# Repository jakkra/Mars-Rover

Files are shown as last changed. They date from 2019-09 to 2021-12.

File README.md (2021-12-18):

<div align="center">
  <h1>Mars Rover</h1>
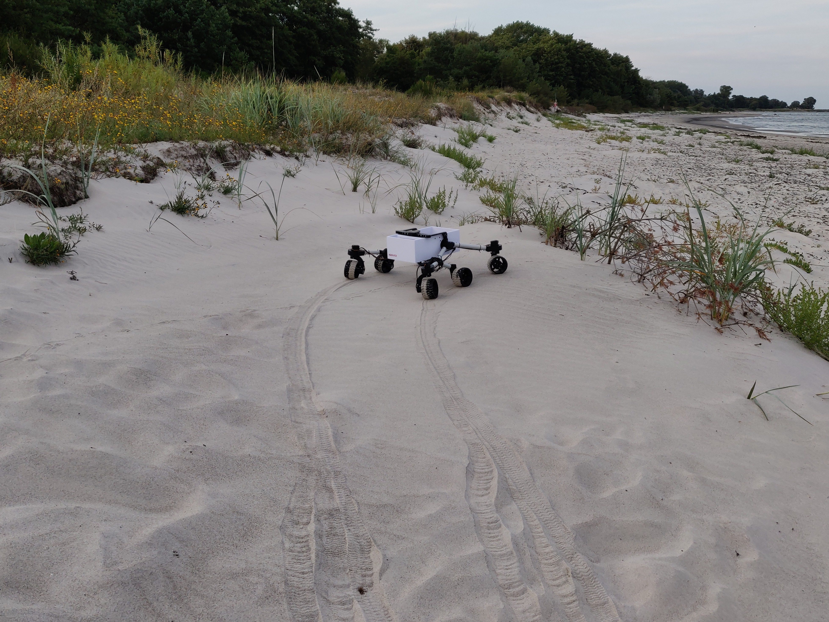
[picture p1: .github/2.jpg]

<sub>
  Curiosity/Perseverance inspired Rover
</sub>
</div>

---

Controller for driving the Rover found here [https://github.com/jakkra/RoverController](https://github.com/jakkra/RoverController).
## CAD model
The whole Fusion 360 project can be found in the CAD folder, download the .f3z file and open it in desktop Fusion 360. 

The CAD render images are more up to date than the real images of the rover, for example some cosmetics have been added and the high gain antenna which can be rotated by a servo.

### Wheels
There are two options for wheeles, either original Curiosity style wheels that print in one piece. Or Mars 2020 style wheels that print in two parts where outer part can be printed in flexibale plastic such as TPU. The rover_2020_wheel_flex.f3d wheels are preferred if your printer can print in TPU as they provide way more grip.

## Driving
There are 3 ways to drive the Rover right now:
- LoRa
- Websockets
- Generic RC Transmitter

By moving a 3 way switch on the rover, the startup mode can be choosen; WiFi station + LoRa, LoRa only or WiFi AP (when using website hosted on the Rover, see data folder).
[Here](https://github.com/jakkra/RoverController) is my controller supporting both LoRa and websocket control of the Rover.

### Telematics
Rover will automatically send telematics data as soon as someone connects to the websocket server or over LoRa if Rover is being controlled ove LoRa.

## Hardware
- 6 12V 60 RPM DC motors, one in each wheel (https://github.com/jakkra/Mars-Rover/issues/6)
- 2 brushless ESC's one for each side (3 motors)
- Lots of (12, one for each servo) 12V to 5V switching voltage regulators
- 4 servos (MG946R/MG996R) on each corner wheel to steer.
- 6 Servos (MG946R) in the arm for 6-DOF. Poweded by a 3S battery. 
- 2 servos (MG946R/MG996R) for the head.
- 6 Channel RC receiver and transmitter
- 6 Motor shaft adapters https://www.pololu.com/product/1081
- Some Round Metal Servo Arm 25T Disc Horns.
- MCU (ESP32)
- 3S battery
- Standard PVC pipe with inner diameter of 23.40 mm and outer diameter 25 mm.
- Lots of screws and bolts, mostly M3, but some M4's too.
- Two kinds of bearings: 5x 608ZZ and 5x 25mm SKF 6005
- Check the Fusion360 project for more details.
- Cable madness is TODO to fix (temporary fixed by hiding it under the "lid")

## Building
There is no manual, but downloading the CAD model and browsing through it should get you started. Browse through both open and closed issues for help. Feel free to open an issue if you have a question. 

## Images
Videos:
- Showing the boogie mechanism in action [https://imgur.com/4UIsRLl](https://imgur.com/4UIsRLl) 
- Arm [https://imgur.com/KY5ioLb](https://imgur.com/KY5ioLb)
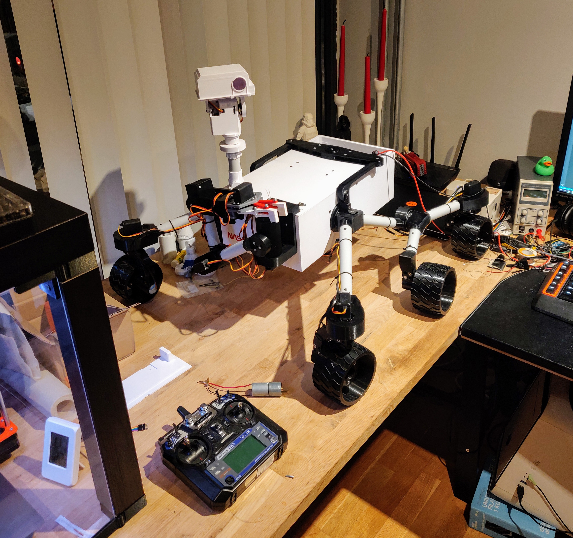
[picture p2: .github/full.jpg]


<p float="left">


</p>
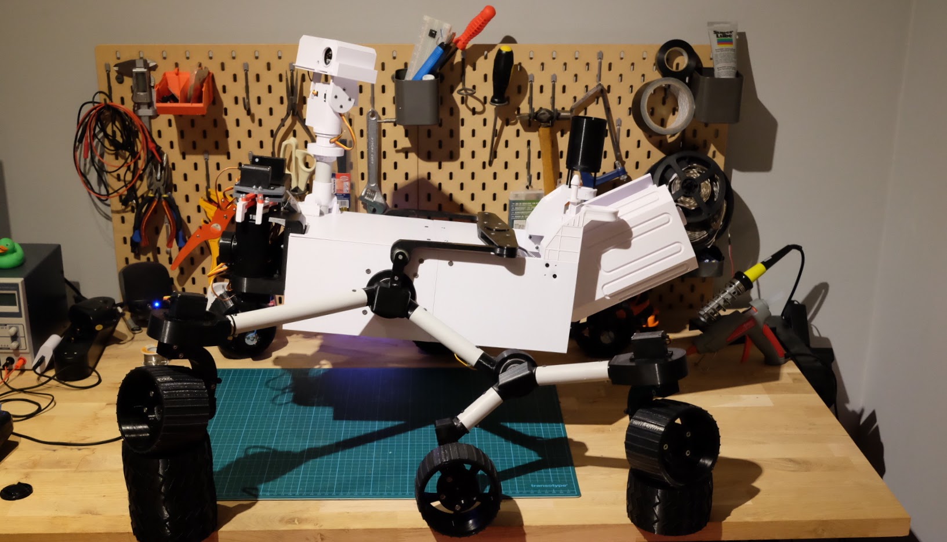
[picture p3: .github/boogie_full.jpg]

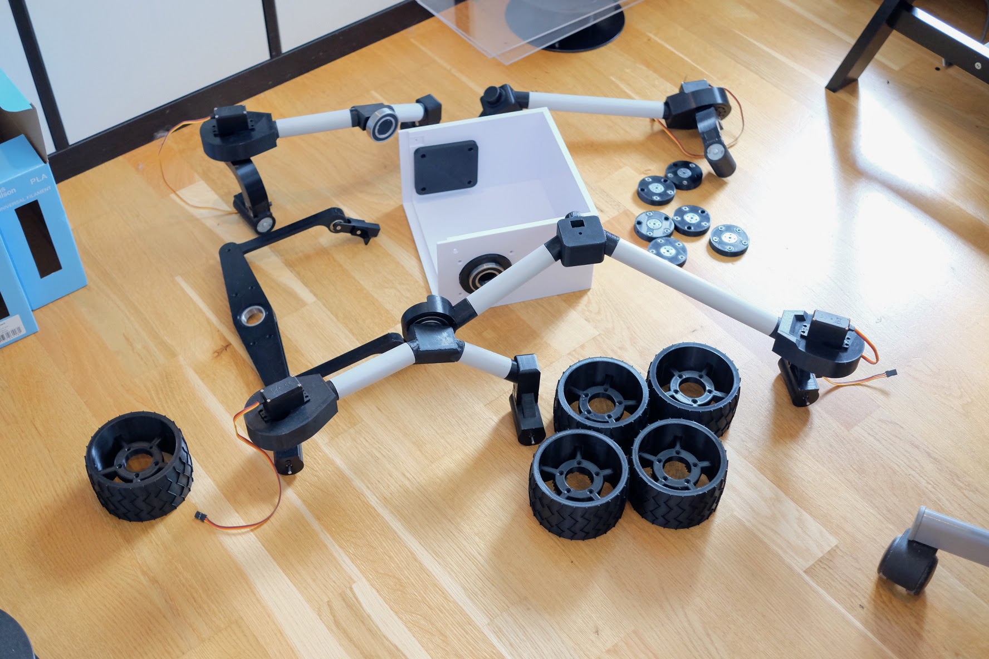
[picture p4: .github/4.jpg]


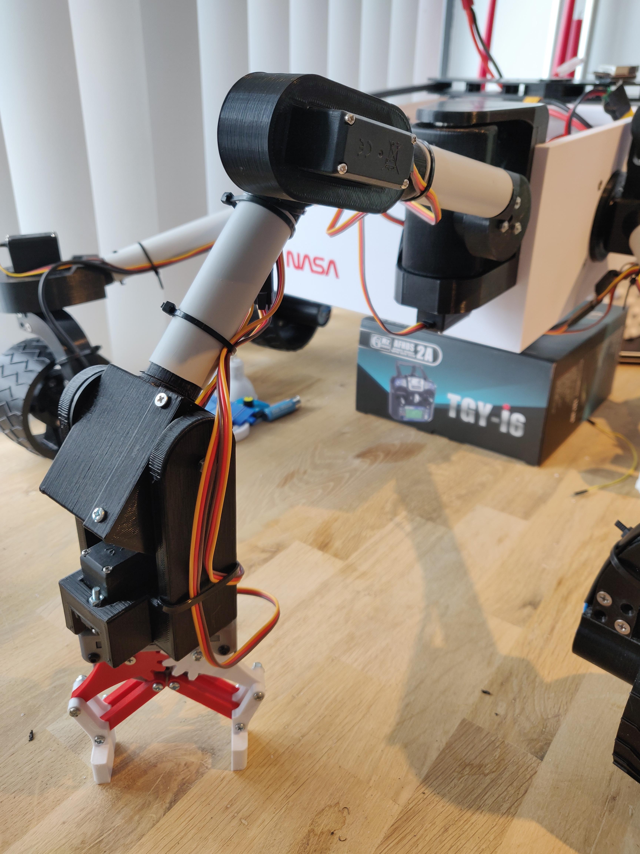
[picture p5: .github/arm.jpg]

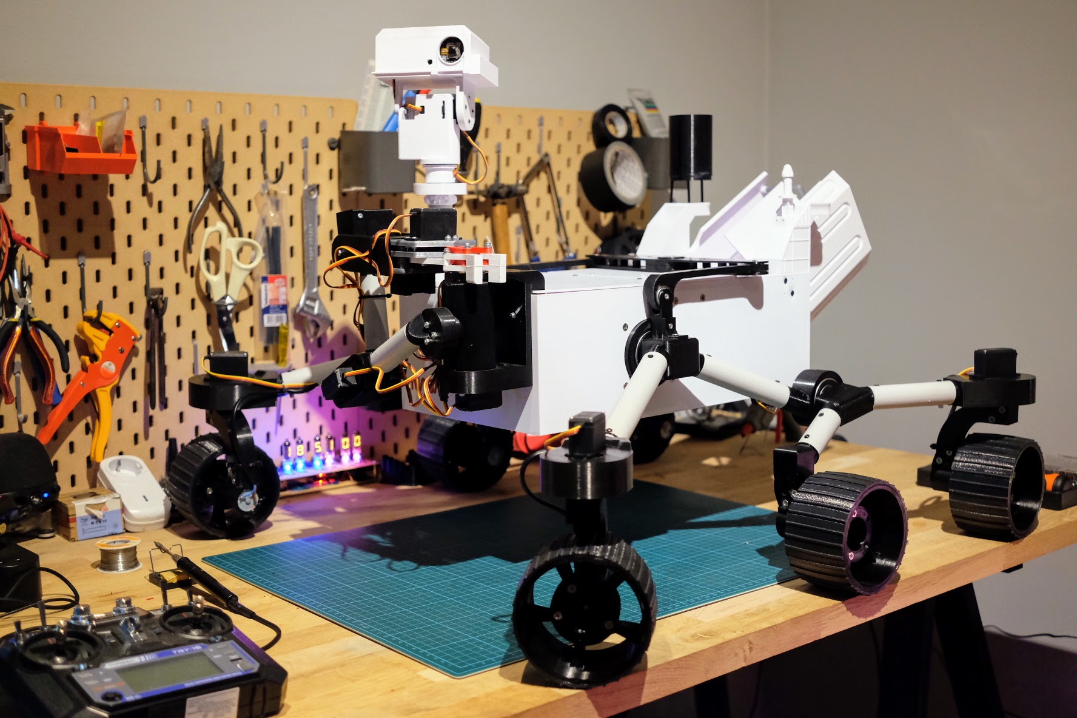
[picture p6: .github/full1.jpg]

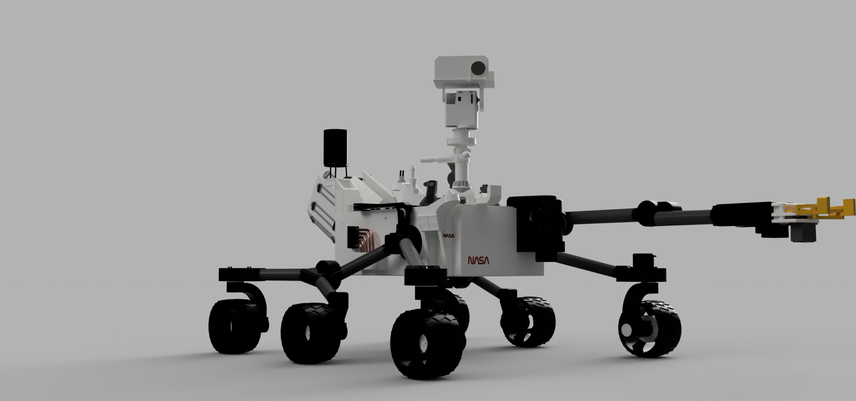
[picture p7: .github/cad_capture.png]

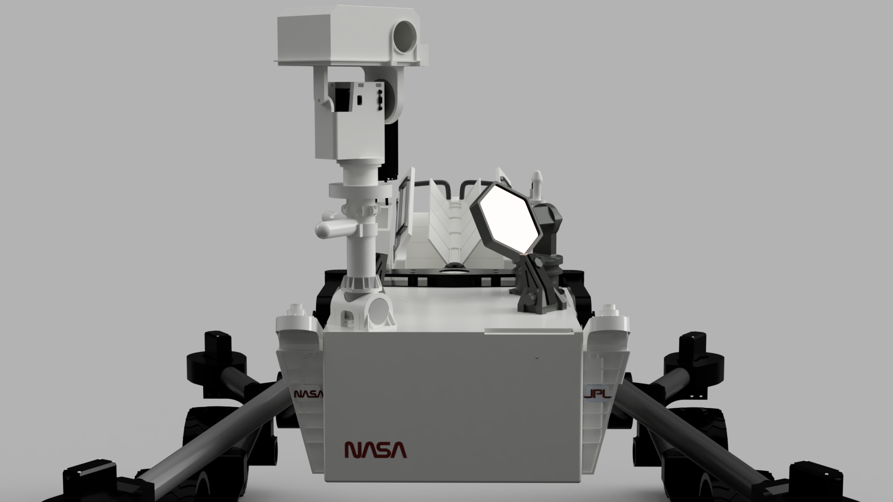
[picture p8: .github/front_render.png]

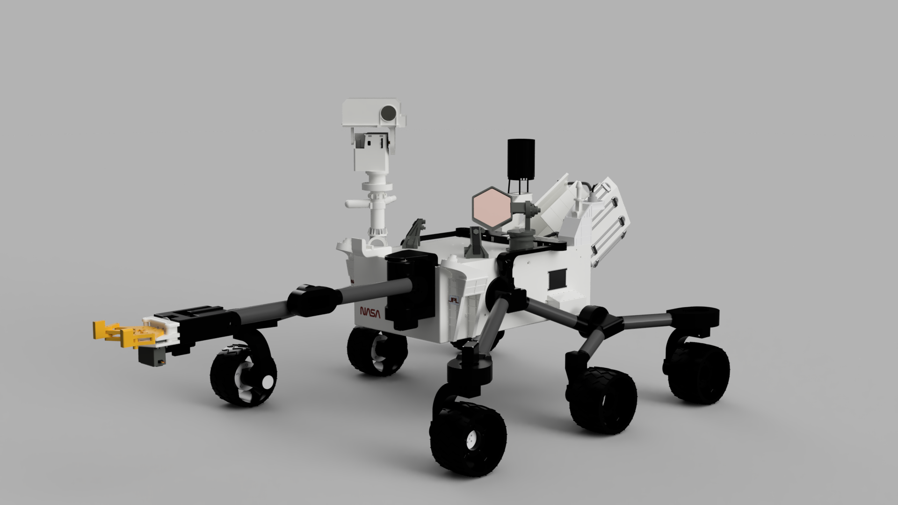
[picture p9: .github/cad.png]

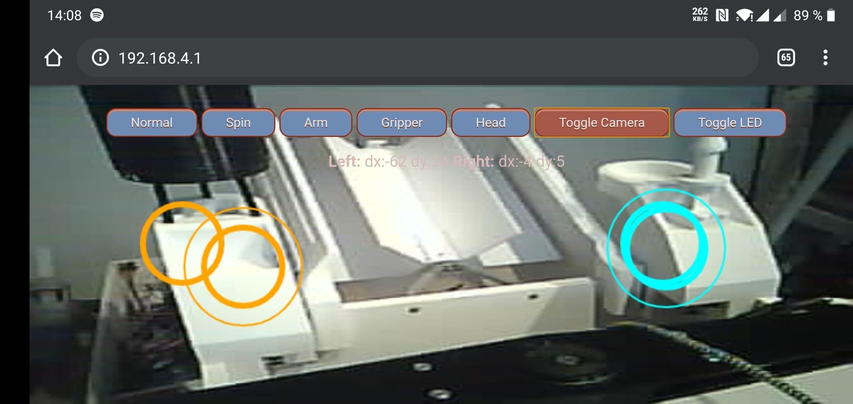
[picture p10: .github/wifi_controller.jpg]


## Driving Modes
There are three ways to drive the rover. Either using a RC controller, LoRa or from a website hosted on the ESP32.
RC controller is deafult, but as soon as someone connects to the ESP32 AP and a websocket is created, the RC controller or LoRa will be overriden by the WiFi controller.
The website functionality is just as basic as the RC controller right now, but the plan is to add more advanced functionality to the website which is not possible to do on the RC controller.
On the RC Transmitter I use two joysticks for channels 1-4 for, and two switches for channel 5-6.
Joysticks are used both for steering the Rover and for moving each axis of the arm.
When switch1 is:
- LOW: joysticks are used for driving the rover
- MID: Wheels will be set correct angles for the rover to be able to rotate on the spot by running each side of wheels in opposite direction. The direction is descided by the steer joystick.
- HIGH: Arm mode, the two joysticks are used for moving axis 1-4 on the arm. Switch2 is used to switch between moving axis 1-4 and axis 5-6 (the gripper). This will be changed in the future, steering each axis manually is not really a good way, inverse kinematics is TODO.

## Arm
Currently arm is just pretty much mapped to controls on the Controller, this is not really useful, so TODO.

## Misc

### Uploading Controller page to Spiffs
```
pio run -t uploadfs
```

### Decoding crashes
```
xtensa-esp32-elf/bin/xtensa-esp32-elf-addr2line.exe -pfiaC -e /c/Users/ijakk_000/Documents/Rover-code/.pio/build/esp-wrover-kit/firmware.elf 0x00000000:0x3ffb5c60 ...
```

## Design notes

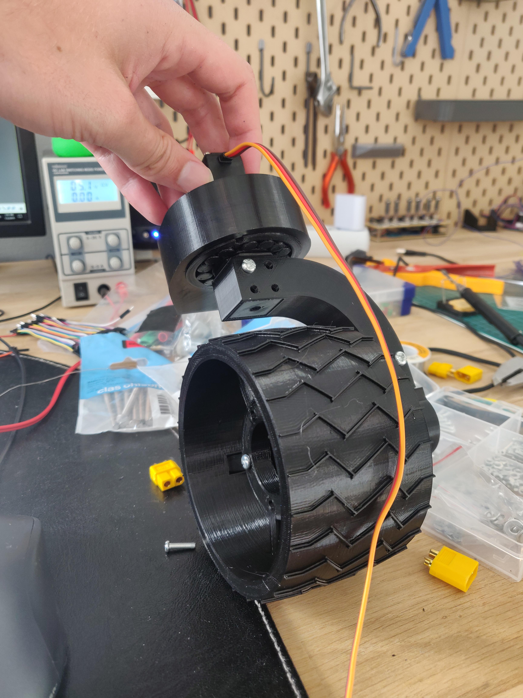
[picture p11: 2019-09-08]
.github/bearing_wheel.jpg

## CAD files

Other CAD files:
CAD/rover_2020_wheel_flex.f3d

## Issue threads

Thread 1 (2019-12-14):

Tubing

fabriziofiorucci, 2019-12-14:
Hello, thank you for sharing this very interesting project: far as I can see the rocker bogie tubing is not printed but looks like standard pvc tubing: what thickness did you select?
Thank you

fabriziofiorucci, 2019-12-14:
Solved! Measured from the f3d body

jakkra, 2019-12-14:
Hi thanks!

I was just about to send you this:
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
Yes it's some standard PVC pipe I found to save some printing time.
In Fusion 360 modify -> change parameters you can see the diameters.
I do hover doubt it's going to work just changing the setting there.

fabriziofiorucci, 2019-12-14:
Thank you! Just started printing the whole rover using asa-x filament

jakkra, 2019-12-14:
Awesome, good luck! I'm sure thats better than the cheap standard PLA I have printed with.

hoonkai, 2020-04-27:
@jakkra Hi What sort of adhesive did you use to attach the PVC and the parts together?

fabriziofiorucci, 2020-04-27:
@hoonkai in case this can help, please see here https://github.com/jakkra/Mars-Rover/issues/12#issuecomment-620130493

jakkra, 2020-04-27:
Hi @hoonkai, the fit is pretty tight but still needs something more to make it 100%, I just drilled a hole straight through and put a screw through like this:
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

Closed 2019-12-14.

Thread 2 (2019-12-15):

Electronics schematics

fabriziofiorucci, 2019-12-15:
Hello, could you share the electronics schematics?
I’m building the electronics based on a raspberry zero and that would come handy.

Thanks!

jakkra, 2019-12-15:
I did draw a not very detailed, but good enough psuedo schematic a while ago. This was from before I added the arm and head. Now I have a I2C servo expander which all servos are connected to for saving pins on the ESP32.
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

fabriziofiorucci, 2019-12-15:
That’s a good starting point: what ESCs do you use?

fabriziofiorucci, 2019-12-15:
I have a fully working design using 6 L298N drivers for the six dc motors, I’m evaluating whether to switch to ESCs

jakkra, 2019-12-15:
I'm using 2 of those with 3 motors connected to each of them
https://hobbyking.com/en_us/hobbyking-x-car-45a-brushed-car-esc.html
So I don't have control of each motor individually, only each side.
I don't see a problem using 6 L298N as long as your DC motors doesn't draw more than 2A under load.

fabriziofiorucci, 2019-12-15:
Thanks: I actually am revamping a former rover I built using aluminium instead of plastic, and a lead acid battery instead of LiPO, with the aim of getting a self guided rover using a control software written in Java. Spare time permitting I might upload some contribution to add distance sensors, lidar etc.

jakkra, 2019-12-15:
Awesome! I'll also add more sensors after I finish the designing and printing the "back" parts of the rover.

I'm thinking of giving https://nasa.github.io/openmct/ a try for ground control software (the UI). I'm also looking for a new radio to get better range and to be able to stream low res video from ~1000m distance. Yet to find a suitable radio technology.

fabriziofiorucci, 2019-12-15:
The openmct project looks quite interesting: on my existing rover I added a GPS receiver and a digital compass and accelerometer, they work quite fine. By saving weight switching from aluminium to ASA and from lead battery to LiPO I might be able to put more stuff on it.
I'm experimenting a bit with LoRA for long range telemetry, but it's way too slow for video streaming, please keep me posted on your findings in that area.

fabriziofiorucci, 2020-01-13:
Hello, for the sake of curiosity, what kind of DC-DC stepdown converter do you use for servos? I'm running on MG996R that have a stall current of ~2.5A so I was wondering, additionally, if you're using one stepdown converter per servo or what else.

Thank you

jakkra, 2020-01-13:
Hi, I'm using variable buck converters like those: https://www.amazon.com/dp/B01MQGMOKI/ref=psdc_10967761_t1_B0758ZTS61
One for each servo (which is kind of a pain)

fabriziofiorucci, 2020-01-13:
Thank you!

fabriziofiorucci, 2020-03-23:
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

Electronics work in progress...

- main board with Raspberry Zero, GPS receiver, magnetometer/accelerometer and ADC for distance sensors
- rocker bogie board with PWM controller for steering servos and control logic for L298N boards

jakkra, 2020-03-24:
Looking good! I finished re-routing my wires so now everything is inside. Currently in progress building a controller using Lora.

fabriziofiorucci, 2020-03-24:
LoRa is in my todo list: will you use it for both control and telemetry? Would you mind sharing some details? I guess you’ll use arduino/wemos, I’ll try the Raspberry way

jakkra, 2020-03-25:
My plan is to use it both for control and telemetry, however I have not yet experimented to see how much the lag is. The idea is to use WiFi control when the rover is close and  switch over to Lora when range increases. I'm going to use two TTGO LORA32, replacing the ESP32 dev kit in the Rover with this board with an ESP32 + Lora transceiver and the other board will be in the controller.

fabriziofiorucci, 2020-03-25:
That sounds really interesting. Please keep us posted!

fabriziofiorucci, 2020-03-29:
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

main board and rocker bogie board assembled and tested, ready to be installed

fabriziofiorucci, 2020-04-03:
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

Ready for testing

jakkra, 2020-04-07:
Looks clean! My current progress:
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
Will have a tablet holder on top also for telematics display.

fabriziofiorucci, 2020-04-07:
it looks great! Will you share the f3d model?

jakkra, 2020-04-08:
Of courese!

fabriziofiorucci, 2020-04-08:
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

My high level electronics design, based on Raspberry Zero WH and I2C everywhere.

fabriziofiorucci, 2020-04-24:
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

Arm and head control board

fabriziofiorucci, 2020-04-24:
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

Closed 2020-04-26.

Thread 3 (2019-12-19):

Steering ball bearing - best way to print

fabriziofiorucci, 2019-12-19:
Hello,

what's the best way to print the steering ball bearing? (see image) all in one print? body by body? I'm thinking to give it a try with 0.12 layer thickness and 30% infill. Did you print it or buy a ready-made one?

Thank you

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

jakkra, 2019-12-19:
Best way to print is like that. I printed with 0.2mm layer height. The infill I don't remember, but 30% sound ok. You might need to modify some clearences depending on your printer. I had to experiment a few times to get it as "stiff" but still rotating as possible. I think I have this bearing in a spearate Fusin360 project where you can modify some parameters. I'll do that when I get home tonight. But give it a try with current setup, it might work good for you.

fabriziofiorucci, 2019-12-19:
Thank you for the details, I’m printing on a creality ender 3, I’ll give it a try tonight.

fabriziofiorucci, 2019-12-20:
Hello again, would you have by chance che fusion project that allows changing clearances? I tried a few prints fiddling with slicer parameters with no success.
Thank you

jakkra, 2019-12-21:
Rename extention to .f3d from .txt as GitHub doesn't allow all file formats to be uploaded.
This is the bearing sketch, you can edit the parameters in the menu modify -> change parameters.
The base comes from thingiverse, but don't remember exact which thing. But here's the sketch.
[608zz10.txt](https://github.com/jakkra/Mars-Rover/files/3991388/608zz10.txt)

fabriziofiorucci, 2019-12-21:
Great, thank you! Meanwhile I’m at 25% of the overall rover body and rocker print. Hope to get the metal ball bearings soon. As soon as the electronics are fit I’ll post some more details.

jakkra, 2019-12-21:
Awesome, good luck!

Closed 2020-01-07.

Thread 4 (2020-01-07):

Best support type to slice & print body

fabriziofiorucci, 2020-01-07:
Hello,

I'm proceeding with all prints, and when it comes to the body I wonder what's the most efficient support type to use when slicing stl files: I'm using Cura and I usually use the default line with 10% spacing. Any hint here/what have you used?

Thank you

jakkra, 2020-01-07:
I'm using Slic3r/PrusaSlicer, for supports I have just used the default ones in my slicer, so can't help you with which are best in Cura. Most parts don't need supports or just need some very simple ones. If you can give me a specific part, I can probably figure out how I printed it and send a image from my slicer.

fabriziofiorucci, 2020-01-07:
Hi, thank you. Most parts are perfectly designed to require a minimum amount of supports (good job!). The only parts I would need a hint is the main body (rover_body_front and the back part), it's quite large and I would like to minimize filament waste by optimizing the (large) support area.

jakkra, 2020-01-07:
I'll be home in an hour ish, will send you some images then.

fabriziofiorucci, 2020-01-07:
Thank you!

jakkra, 2020-01-07:
No supports needed for the front, printed fine on my MK3, should be fine on your Ender 3 too.
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
Only required supports for back are those two.
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

fabriziofiorucci, 2020-01-07:
Thank you again! Cura tells me that I'm really hitting the width limit of the print bed and hence I should print it lying on one side. I'll try to fiddle with some parameters to print it the way you did. I'll keep you posted.

jakkra, 2020-01-07:
Yeah I printed it pretty much to be as big as I could print. You can in worst case just make the main rover body a cm och 2 shorter to make it fit.

fabriziofiorucci, 2020-01-09:
Hi, I managed to fix the printing area. I was wondering what infill and layer thickness you used. I would go for 20% and 0.24, that would be roughly 500g of filament and a couple of days of printing time.
Thank you

jakkra, 2020-01-09:
Great! I used 0.2mm layer thickness, and fairly low infill, maybe 5%. If i recall correctly the main body took about a day for each half to print.

fabriziofiorucci, 2020-01-09:
Thank you, I’ll try with that!

jakkra, 2020-01-10:
I looked a bit closer on my Rover and see that I used 3 perimeters for the bodies, instead of default 2.

fabriziofiorucci, 2020-01-10:
Thank you! I’ll change slicer settings accordingly

fabriziofiorucci, 2020-01-18:
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

currently printing the first half of the body: it takes the whole print area, thank you again!

fabriziofiorucci, 2020-02-22:
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

Body and rocker bogie prints came out perfect, next step: putting together the electronics

fabriziofiorucci, 2020-02-22:
Had some cracking issues while printing the body with ASA, so I switched back to PLA

jakkra, 2020-02-22:
Wow that's awesome! Feels weird to see it on other than my colors, but it looks really good 👍
Good luck with the electronics, that's the easy part IMO :)

Here's a peek in what I'm currently working on, upgrading the wheels to flexible wheels for better grip (also upgradade to Rover 2020 look of the wheels, however I prefer the look of the old ones, but printing the old style in flex filament didn't turn out so good).
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

I also decided to finally clean up the wiring a bit, work in progress.
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

PS. I'll re-open this issue for better visablity for others :)

fabriziofiorucci, 2020-02-22:
Flexible wheels look great! I'm quite curious to see how ASA will react to friction when I start letting it run. Did you print the flexible part in TPU?

jakkra, 2020-02-22:
I think the ASA will do pretty well, I do not se much wear on my PLA wheels, and ASA should be comparable if not a bit stronger.
I actually don't know, bought it from a local store and it's unlabeled, but I would guess it's TPU.

Closed 2020-04-26.

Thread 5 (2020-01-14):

Body drillings

fabriziofiorucci, 2020-01-14:
Hello,

the rover_back v1 f3d file shows a number of holes on the back part of the body (to attach reactor and antenna) and on the front part (arm). Since I'm quite new to fusion 360, how can the body STLs be exported, so that they include all holes?

Thank you

jakkra, 2020-01-14:
Hi thanks for finding this, looks like I forgot to do that as I just drilled those holes manually. I did not want to reprint the whole body. I have added the missing holes in this commit: 415d6b2ec4bc9af1005ce21a38afaa425a376768
Please check if I missed some.

I need to see if I can restructure the Fusion project a bit, I did not fully understand how to correctly work with components when I started which makes things like this those holes a bit wierd to add.

fabriziofiorucci, 2020-01-14:
Thank you, I'll check and will let you know

fabriziofiorucci, 2020-01-22:
Hi, the front part of the body with the arm hole printed perfectly in slightly more than two days. I'm now printing the rear part.
Thank you for helping!

Closed 2020-01-22.

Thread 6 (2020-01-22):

what motors did you use

gitnem, 2020-01-22:
First off thanks for all the hard work you have put into this project.  I am interested in building this, but I am having issues sourcing a 25mm x 56mm brushless dc motor.  I would like to know which ones you choose to go with.

jakkra, 2020-01-22:
Hi, try searching for "brushless DC motor 12v 12v 60rpm" and you find some. Maybe this one:
https://a.aliexpress.com/_rvIAA0
Or this one: https://banggood.app.link/fPmdq9zPs3

However I see that the banggood one does not have a suitable rpm optional, but it might help you find one that will fit. The length of the motor is not that important, it will fit anyway.

You can also edit the Fusion design if you find some other motor you want to use.

fabriziofiorucci, 2020-01-22:
I got them from here:

€ 2,70  16％ Off | JGA25-370 Geared motor DC motor 6V 12V electric gear motor high torque 5/10/15/30/60/100/150/200/300/400/500/1000/1200 rpm
https://a.aliexpress.com/_UBuPo

You can select the rpm you need

gitnem, 2020-01-22:
thanks for all the info.  I noticed in another post you are using the https://hobbyking.com/en_us/hobbyking-x-car-45a-brushed-car-esc.html ESC, but your battery system is 3s (~12v).  The data sheets for that ESC say it needs 2s input, are you feeding 12v to the ESCs or do you have a step down?

Put another way, will feeding 3s to those ESCs harm them or not provide enough voltage to the motors?

jakkra, 2020-01-22:
Yes I know the ESCs are running out of spec, but they are very cheap and I have so far not had any problems using them at 12v. I'm sure it's not good to run them at 12V. The DC motors max out at less than 2 amps at stall, so that's max 6 amps and the ESCs are rated for 45A.

Closed 2020-01-23.

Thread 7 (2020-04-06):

STL Files

BarryReid, 2020-04-06:
Hey, just wondering if there are any pre generated STL files available or if everyone is just creating their own from the CAD?

jakkra, 2020-04-06:
I have not generetaed the STL files, and I don't really want to do that every time I update something. So the idea is to download the Fusiom 360 project and export the STLs from there.

BarryReid, 2020-04-06:
All good! Just wanted to make sure I was not missing something.

Smarty-pro, 2020-07-23:
Hey, @jakkra I just found the 3d model of Curiosity made by NASA if you want to make your rover design more realistic https://github.com/nasa/NASA-3D-Resources/tree/master/3D%20Models/Curiosity%20(Clean)

jakkra, 2020-07-23:
@Smarty-pro Cool!

Closed 2020-07-23.

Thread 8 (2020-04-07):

Bearings

BarryReid, 2020-04-07:
I just bought some of the large size bearings and was wondering how people are securing them into position (main_leg_body_connector to the leg_boddy_bearling_connector).

jakkra, 2020-04-07:
For me the print is real tight so I had to really force the bearing in place so they sit there without anything additional. But if the fit is not perfect you could use some Loctite super glue, I use that in some places, for example to get the small bearings to stay.

fabriziofiorucci, 2020-04-08:
In case this might come handy: I printed the rocker bogie part using ASA-X and the body and arm with PLA. PLA prints (at least on my Creality Ender 3) came out perfect, whereas ASA-X shrunk a tiny bit while cooling down, even if my printer runs inside a temperature-controlled enclosure. In such a case the rocker bogie ball bearings were a bit loose. I solved that by simply designing and printing with PLA a very thin "adapter ring", basically a cilinder fitting the gap between the rocker bogie assembly and the ball bearing iself.

I preferred not to use glue in order to be able to disassemble parts in case I need to in the future.

I hope this helps.

fabriziofiorucci, 2020-04-10:
[Ball bearing adjustment.f3d.gz](https://github.com/jakkra/Mars-Rover/files/4460779/Ball.bearing.adjustment.f3d.gz)
[Ball bearing adjustment - steering wheels.f3d.gz](https://github.com/jakkra/Mars-Rover/files/4460780/Ball.bearing.adjustment.-.steering.wheels.f3d.gz)

In case this can help, here's the adjustment rings I designed.

Ball bearing adjustment.f3d can be used to fill the gap between the body and the main rocker bogie bearing
Ball bearing adjustment - steering wheels.f3d can be used to fill the gap between the four steering bearings and the rocker bogie printed part

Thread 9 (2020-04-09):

Grip rotator and servo insertion

fabriziofiorucci, 2020-04-09:
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

Hello,

I'm in the process of assembling the arm: when it comes to the grip rotator, how did you manage to install the servo? The print came out perfect but the servo doesn't slide in since the protruding rubber part where the power+pwm cable comes out leaves no space to insert the first part of the servo diagonally and then slide it in. Did you cut away some part somewhere?

Thank you

jakkra, 2020-04-09:
Ah yeah that one, I didn't think of that when designing it. What I ended up doing was to unscrew the "backplate" on the servo so that the wires wouldn't block and then put the servo together again after put in place.
By the way I didn't expect anyone to build the arm, so note that the design is far from perfect and has flaws.

Also now while studying the cad I realised I missed fixing the design for a hole I missed, see attached image for where to drill manually.
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

fabriziofiorucci, 2020-04-10:
Thank you! I'll assemble it later on today, the clamp works fine, just the right amount of friction. When I finish writing the software part I'm thinking about designing an interchangeable head in order to mount multiple tools like clamp, drill, laser head, etc.

fabriziofiorucci, 2020-04-10:
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

so far so good :-)

jakkra, 2020-04-10:
Awesome! I also shortened the PVC pipes quite a bit in the arm because the servos had some problems when they where as long as in the design. But since it's just PVC pipe you can easily experiment on what length works best for you, shorter => easier for servos.

Interchangeable heads sounds awesome :) Really need to do the math for the arm (inverse kinematics) for it to work good, I haven't felt for doing it yet, but I hope I will some day.

fabriziofiorucci, 2020-04-10:
That's interesting: would you mind sharing the PVC pipes length you're currently using? So that I don't reinvent the wheel, I'm using al MG996R servos so they're pretty much standard.

jakkra, 2020-04-10:
Sure, both are 8 cm. I use the MG946R in the arm as they have about 13kg/cm more torque compared to MG996R with 11kg/cm, but have the exact same dimentions. I have also bough this servo http://www.goteckrc.com/ProductShow.asp?ID=52 for use here
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 which is 20kg/cm @7.4V, however I have not tested it yet. Should be alot stronger I think. That servo is the one with the most load.

Also note that there is difference between MG996R anf MG996R depending on brand, I have both from Towerpro and some clone brand, and the ones from Towerpro are way stronger, even if the models are the "same".

fabriziofiorucci, 2020-04-10:
Thank you, all of my servos are tower pro, I will see how they perform once assembled.

fabriziofiorucci, 2020-04-26:
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

Arm assembled, all parts came out perfectly.

jakkra, 2020-04-26:
Awesome! Looks cool! Now just some cable management, good luck :smiley:

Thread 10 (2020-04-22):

Servos don't fit

BarryReid, 2020-04-22:
Hi Guys

I bought TowerPro MG946R's for the steering as stated in the readme but after printing the wheel rotors they don't seem to fit at all. Just wondering if I am missing something.

jakkra, 2020-04-22:
The margins might be a bit tight, and differences between printers could cause servostyrning to not fit maybe. Is it way off, or could you sand the print a bit to get it to fit?

BarryReid, 2020-04-22:
Ye its quite a bit off and my printer is pretty accurate. I see in the cad model the server you have a model for is the MG996R not the MG946R like you have recommended in the docs. Could there be a difference there?

fabriziofiorucci, 2020-04-22:
Hello,

margins are a bit tight indeed, but the overall assembly has to be sturdy, so it makes sense. I use a Creality Ender 3 and in some cases my servos (TowerPro MG995R) fit perfectly, in some other cases I needed to use a dremel with a sandpaper tip to allow for a bit more space. I didn't print/use the wheel rotator, I decided to use the stock aluminium rotator that comes with the servo.

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

fabriziofiorucci, 2020-04-22:
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

BarryReid, 2020-04-22:
Ye those MG996R's must be a different size, you may want to update your doc on the front page as the MG946R's are quite a long way off (not just a snug fit) their mounting holes also don't line up.

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

jakkra, 2020-04-22:
You can just bend those "pins" off from the print. I did that now I remember. Will work anyway. Do they fit otherwise?

BarryReid, 2020-04-22:
No servers are still too big to fit even with a bit of force :) I will try shaving off some plastic from the part and see how its goes.

jakkra, 2020-04-23:
Like @fabriziofiorucci says, most parts in the rover work better if they are a tight fit. Some part might need some sanding to fit. If you are very far off, then come back and I'll update the model to give a litte more room for the servos.

fabriziofiorucci, 2020-04-23:
If I can add a bit/if this can be useful: I printed the rocker bogie assembly and wheels using ASA-X and my homebuilt heated printer enclosure (without it I can't simply print ASA-X due to cracking/warping) and after printing there is some shrinkage anyway, so steering servos were a bit tight (some sanding solved that).
When printing the body and arm I went for PLA and here warping/shrinking is virtually non-existing: when fitting the servos I needed to sand it even more if compared to the rocker bogie.

jakkra, 2020-04-23:
I will increase the margins around some servos next time I'm working on the Rover model (unless @BarryReid can't sand around it)

By the way a little teaser:
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

fabriziofiorucci, 2020-04-23:
This is super cool! When are you going to post the f3d files? ;-)
At the end of the day did you go for LoRa+WiFi?

BarryReid, 2020-04-24:
Hey, ye if we could get a bit more space in the model that would be great, I need to sand so much that the walls of the print are almost non existent. I think this version of the servo is just a bit wider than the MG996R

BarryReid, 2020-04-24:
When I get home I will send you the measurements of the MG946R

jakkra, 2020-04-24:
Ok, that's a bit to much to sand, I will update the model tomorrow! I'll compare it with my servos and see how off it is.

For the controller, yes I went with both wifi and lora. Code, CAD and website for the phone is all about 80% done. Have not finished final design of the back of the controllers yet. I'll probably finish it up the next 2 weeks and make the repository public.

jakkra, 2020-04-25:
Realised the servo model I have used for reference is a about 1mm than the real one.
I measured my MG946R and MG99R and they have the exact same size. I made some more room in the "`original_wheel_rotor`" parts. Will those dimentions work for you?
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

BarryReid, 2020-04-26:
Mate that's should be perfect! Did you make the change on the back and front rotors? I tried to download to check but cant see the updated CAD model in the GIT.

jakkra, 2020-04-26:
No, I didn't upload, wanted to get ok from you first. Will update asap.

BarryReid, 2020-04-26:
Thanks mate, did you make the change on the back and the front rotors?

jakkra, 2020-04-26:
Yes all 4.

BarryReid, 2020-04-26:
Hey @jakkra thanks so much for making those changes. I printed this part again overnight and have just completed a test fit.

It now however seems to be a bit loose. Just wondering if you expanded it by a total of 1mm or if you did 1mm on each side?

I think if we made it half way between what it is now and what it was, it would be prefect.

Hope the feedback helps.

jakkra, 2020-04-27:
No, I did 0.5 on each side, so in total 1mm. If it can move inside then it's a problem, but otherwise I don't think your print is wasted, it should be hold in place when servo head I screwed in place. But anyway I'll update the model tonight with 0.25mm on each side instead of 0.5.

BarryReid, 2020-04-27:
Yip it moved ever so slightly. I think 0.25 on each side will be the perfect amount. The print should not be wasted as I will just glue in some single layer shims on each side of the servo. I will print the final rotor once you have updated the CAD and let you know the outcome.

Thanks

jakkra, 2020-04-27:
Feel free to print the final rotor now, I have now updated the dimentions.

k4m454k, 2020-05-23:
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

Same problem with TowerPro MG996R
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

BarryReid, 2020-05-23:
Ye, I just snapped them off, drilled some tiny pilot holes and screwed them in with a few self tappers.

k4m454k, 2020-05-23:
> Ye, I just snapped them off, drilled some tiny pilot holes and screwed them in with a few self tappers.

Barbarian =)

jakkra, 2020-05-23:
Yeah just snap them off, seems as the distance between the holes as a bit different between some brands of MG966R. They don't really do anything.

k4m454k, 2020-05-23:
> Yeah just snap them off, seems as the distance between the holes are a bit different between some brands of MG966R. They don't really do anything.

I just redid this element and re-printed it.  the perfectionist inside me rejoices

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

jakkra, 2020-05-23:
@k4m454k hehe great! There are some things that are not perfect yet in the build, so you might need to compromise with your inner perfectionist some time later :wink:

Closed 2020-04-26.

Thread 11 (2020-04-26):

Software & communications flow

fabriziofiorucci, 2020-04-26:
I'm in the process of writing the control software.
This issue is mostly to share what I'm doing and to collect hints/other views on this topic.

Since my version of this rover is based on a Raspberry Zero WH, for development speed reasons I chose to use Java. I know that performance-wise and memory/CPU-wise it sucks, but there's a ton of ready-made libraries and I don't want to reinvent the wheel.
Namely, what I'm using is:

https://pi4j.com/ - for IMU, ADC, PWM controller, etc, it has lots of libraries ready to use
https://www.eclipse.org/paho/ - MQTT communication
https://eclipse-ee4j.github.io/jersey/ - REST API

I will eventually use WiFI and LoRa for the radio/control part, and all telemetry will be sent by the rover through MQTT. MQTT will also be used for interactive control.

Pre-programmed/batch control will be handled through a set of REST APIs that the code running on the rover will provide.

jakkra, 2020-04-27:
I think that's a great idea. When you have something working and if you release it in a public repo, I'll link to it in a new section in the README "Alternative SW" or similar.

fabriziofiorucci, 2020-04-28:
Hi @jakkra I just created a repo for my control software at https://github.com/fabriziofiorucci/Mars-Rover-Control-Software
As soon as I have an alpha release ready I'll update the repo.

jakkra, 2020-04-29:
Cool!

fabriziofiorucci, 2020-04-30:
Here you go: the pre-alpha release of my repo is ready, still work in progress

https://github.com/fabriziofiorucci/Mars-Rover-Control-Software

jakkra, 2020-05-17:
Nice progress on your control SW!
I just finished my Controller if you are interested https://github.com/jakkra/RoverController

fabriziofiorucci, 2020-05-17:
That looks really interesting! I just completed the first round of driving tests including interactive control (through SSH to the onboard Raspberry PI for now) and through REST API, driven by Postman.

I'm cloning your controller repo and I'll definitely try to build it. Keep up the great work!

Smarty-pro, 2020-07-13:
I don't understand, the 6 Channel RC receiver and transmitter is not enough to control the rover?

jakkra, 2020-07-13:
@fabriziofiorucci Is writing his own controller software for the rover. A 6 ch RC receiver/transmitter is enough for basic control of the rover. Without a microcontroller you are limited to how advanced your RC controller is, i.e. turning on the spot may not be possible.

Smarty-pro, 2020-07-13:
Oh nice

fabriziofiorucci, 2020-07-15:
FYI I just completed printing and adding the head, I'm working on the next commit of my control software + testing LoRA boards to control it remotely.

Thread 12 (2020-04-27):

Tubes

k4m454k, 2020-04-27:
What tubes are used for suspension?  I measured the diameters, 25x22.6 (external / internal).  but I did not find such in stores.

jakkra, 2020-04-27:
Hi, I posted the exact https://github.com/jakkra/Mars-Rover/issues/1#issuecomment-565747755 here: https://github.com/jakkra/Mars-Rover/issues/1#issuecomment-565747755 I bought the PVC pipe in a local store, so I can't really point you anywhere unfortunately. If you find similar pipe, you can edit the dimensions in the model yourself.

fabriziofiorucci, 2020-04-27:
Hi @k4m454k I used regular pvc tubes with an internal diameter of 20mm, I worked a bit with a dremel and sandpaper head to enlarge the tube's inner diameter and to scratch a bit the outer diameter of the printed parts. It took a while but I didn't want to print everything again and, on the nice side, the fittings are extremely tight, and the overall rocker bogie is very sturdy.
I hope this helps.

k4m454k, 2020-04-28:
Great! Thank you!

Closed 2020-04-28.

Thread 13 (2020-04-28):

Mounts inside the bearing

k4m454k, 2020-04-28:
Hello.
I did not understand how this part is mounted inside the bearing? What keeps her from falling out?
Could you clarify this issue?

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

k4m454k, 2020-04-28:
Ohh, sorry,
I see it

https://github.com/jakkra/Mars-Rover/issues/8

Closed 2020-04-28.

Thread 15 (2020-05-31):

Servo Horns

BarryReid, 2020-05-31:
Hey Guys

Does anyone have the link they used to buy the disk metal server horns for steering (Some Round Metal Servo Arm 25T Disc Horns.)

jakkra, 2020-05-31:
These are the ones I bought https://www.ebay.co.uk/itm/263283372008 however they are not in stock, but from the description you should be able to find similar on ebay.

BarryReid, 2020-05-31:
found these. Seem to be the only ones that are not going to take 2 months to ship. https://www.amazon.com.au/Mallofusa-Servo-Aluminum-Silvery-Helicopter/dp/B00NOGMK3M

jakkra, 2020-05-31:
Yeah shipping is very slow nowadays, good luck!

k4m454k, 2020-05-31:
Variant from Ali

https://a.aliexpress.com/_eKCy0d

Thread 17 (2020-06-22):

How to print head top connector & head rotator

fabriziofiorucci, 2020-06-22:
I'm trying to figure out how to print the head top connector & head rotator: I see that some bodies need to be exported as a single stl. One thing that is not clear to me is what bodies need to be exported/printed together in the red area here below:

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

Any hint? Thank you :)

jakkra, 2020-06-23:
Just print the parts seperate and glue them together. I also removed some parts that I did not end up using, so please refer to updated CAD model in 1446ce1866cb28418cfaf15fcf79e33b03aeff84
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

fabriziofiorucci, 2020-06-24:
That's clear now, thank you!

Closed 2020-06-24.

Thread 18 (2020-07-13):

What 12V to 5V switching voltage regulators do you use ?

Smarty-pro, 2020-07-13:
First off thanks for all the hard work you have put into this project. I am interested in building this, but I am having issues sourcing a 12v-to-5v-switching-voltage-regulators. I would like to know which ones you choose to go with.

jakkra, 2020-07-13:
Hi, I use buck converters like those https://www.amazon.com/dp/B01MQGMOKI/ref=psdc_10967761_t1_B0758ZTS61 They can be found on many other places too.

Smarty-pro, 2020-07-13:
Thank you :)

Closed 2020-07-13.

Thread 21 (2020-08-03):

Printing tolerances

androiddrew, 2020-08-03:
Hey @jakkra does your design have enough tolerance in the CAD model for direct printing or would I need to account for shrinkage in my slicer?

jakkra, 2020-08-03:
You should not need to shrink parts in your slicer, some parts are a tight fit by design. You may need to sand some parts a bit for perfect fit. Of course it depends a bit on printer calibration also, I print on a Prusa mk3.

So my recommendation is to print as is and then sand if needed, should not be too much.

androiddrew, 2020-08-03:
Ok, sounds great. I was referring to the shrinkage of the plastic as it cools. So printing at 101% scale, which roughly accounts for PLA shrinkage.

jakkra, 2020-08-03:
I think you should print at 100%, I have printed all parts in PLA also so it's designed for that.

Closed 2020-08-05.

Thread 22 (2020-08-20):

Openmct

Smarty-pro, 2020-08-20:
Hello, I recently found a next-generation mission control framework for visualization of data on desktop and mobile devices developed by NASA. This is the link https://nasa.github.io/openmct/

Smarty-pro, 2020-08-20:
It could help you in the web interface of your rover

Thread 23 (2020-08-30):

Can the design drawing of the car provide a SolidWorks version

bluesky-ryan, 2020-08-30:
Dear jakkra:

   Thank you for your selfless sharing. Your rover is very cool. I also want to make one, but Fusion360 is very slow in China, and the license is basically not available. Is there a solidworks version of the car? Whether the bearings on the 4 driving wheels are missing, I wondered how to install them for a long time.

jakkra, 2020-09-02:
Hi, unfortunately from what I know that's not possible. What is possible is to export the Rover in .step format, I think Solidworks should be able to handle that.
From my quick google search Fusion 360 should be fine to use in china and the free hobby license also valid in china. However I tried to export the whole rover as .step so you can try to import that, that's the best I can do. [rover_full.zip](https://github.com/jakkra/Mars-Rover/files/5164127/rover_full.zip)

jakkra, 2020-09-02:
For the bearing see this screenshot:
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

bluesky-ryan, 2020-09-03:
thank you very much!!! love you

bluesky-ryan, 2020-09-08:
Dear jakkra:

    What are the dimensions of these joints? I can’t draw these joints without dimensions.

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

bluesky-ryan, 2020-09-08:
This one I painted is very ugly, and the size is not right at all

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

jakkra, 2020-09-08:
I thought dimentions was included in the .step files. Are you sure you cannot use some measure tool in Soldiworks?

bluesky-ryan, 2020-09-09:
I tried the measuring tool inside, but this kind of irregular curved surface cannot be measured.，very sad. Is it necessary to use the space triangle Pythagorean theorem to calculate the size, mainly to keep the 3 wheels in a straight line and the middle wheel is exactly in the middle?

jakkra, 2020-09-09:
The middle wheel is not in the exact middle. Are you re-drawing the rover in Solidworks? I don't really follow. I can take some measurements if you specify exactly which distances you need.

bluesky-ryan, 2020-09-09:
Yes, on the one hand, some parts have different sizes and need to be redrawn. On the other hand, I also hope to be able to draw pictures by myself like you. I am learning to draw. You are now my idol. The design of the wheel support frame of your car is very ingenious. I have watched it for 2 days and cannot understand your design idea. How do you ensure that the wheels are in the same straight line? The support rods and support points of the rear wheels are not in the same line. This design in a straight line feels very cool, but I can’t understand how you can ensure the exact dimensions.

jakkra, 2020-09-09:
It's not that hi-tech, I just modeled from the ground up:
Created 1 wheel and wheel base, copied it 2 times and put them in a straight line, now we have 3 wheels in a straight line.
Then model the pipe in a direction so it meets the other pipes. Put a large square that connects the pipes coming from each wheel and TADA.

bluesky-ryan, 2020-09-10:
lol..   I thought you designed this frame according to a certain kinematics principle, doing complex calculations, and then started drawing parts according to this frame

Smarty-pro, 2020-09-22:
@bluesky-ryan this is what NASA did, this rover is an imitation of the famous Curiosity rover

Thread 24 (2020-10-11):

question

wmsJackWang, 2020-10-11:
hey ， genius  i am fersh person about Mars-Rover ,  but i 'm  very  carazy about it , could i learn it good from knowing nothing?

jakkra, 2020-10-11:
I don't recommend building it if you know nothing about electronics, 3D printing, CAD and programming. To build it you need to know about 3D printing, you might need to do minor tweaks in the CAD design. You will need to wire everything up. You don't need programming knowledge if you stick with running it without a microcontroller and only using a standard RC transmitter.

Parampatel1813, 2025-02-01:
Yeah man

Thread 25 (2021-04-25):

software

Albertogalvani, 2021-04-25:
Hi, i really like the rover, Nice project!
 is there a guide for people that does not know how to program (like me) to control the rover remotely?

jakkra, 2021-04-25:
Hi, there is no guide, but it not hard to wire it up to a standard RC receiver. That is how I initially ran it (without the the arm). For steering and driving a 6 channel receiver is enough, 4 channels for the four steering wheels, and one channel each for two DC motor ESC:s (one for each 3 side motors). There are a lot of guides on Google and YouTube for setting up a RC transmitter/receiver.

Ivane55, 2024-09-22:
Hi, you have a very interesting project, I want to repeat it, but I'm not strong in programming. As I understand it, in your src folder there are only library files, is there an "ino" file somewhere for flashing the esp 32 module or is the module flashed in some other way?

jakkra, 2024-09-22:
Hi @Ivane55, this is an old project of mine and I don't really remember. Not that long ago another guy built a rover and he documented it a lot better, so I suggest go looking there instead: https://howtomechatronics.com/projects/diy-mars-perseverance-rover-replica-with-arduino/

Good luck!

Closed 2024-09-22.

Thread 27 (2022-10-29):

Arm missing from F3D CAD file

kevwilde, 2022-10-29:
Hi, I checked out the last version for the CAD file but I can only find the arm_holder component in there .. Is there a seperate location for the arm?

Thank you so much for this design!

jakkra, 2022-10-29:
Hi, looks like I accidentally hid the arm parts when exporting the model, so it's still there, just hidden. So for now you can just go in like in the image and click the eye to show all arm components. I'll update the model later with the arm showm by default.
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

Closed 2022-10-29.

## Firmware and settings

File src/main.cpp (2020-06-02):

/*
* Code for controlling my Rover. Controlled using generic 6 channel RC Transmitter, Websocket or Lora.
* 
* On the transmitter I use two joysticks for channels 1-4 for, and two switches for channel 5-6.
* Joysticks are used both for steering the Rover and for moving each axis of the arm.
* When switch1 is:
*   -LOW: joysticks are used for driving the rover
*   -MID: Wheels will be set correct angles for the rover to be able to rotate on the spot
*         by running each side of wheels in opposite direction. The direction is descided by the steer joystick.
*   -HIGH: Arm mode, the two joysticks are used for moving axis 1-4 on the arm. Switch2 is used to switch beween moving
*          axis 1-4 and axis 5-6 (the gripper). This will be changed in the future, steering each axis manually is not really a good way, inverse kinematics is TODO.
*/

#include <Arduino.h>
#include "rover_config.h"
#include <ESP32Servo.h>
#include "Wire.h"
#include "rc_receiver_rmt.h"
#include "wifi_controller.h"
#include "lora_controller.h"
#include "switch_checker.h"
#include "arm.h"
#include "gyro_accel_sensor.h"
#include "rover_servo.h"
#include "rover_head.h"
#include "rover_settings_switch.h"
#include "rover_driving.h"

#include <SPI.h>
#include <LoRa.h>

#define DEBUG

#define ACCEL_READ_PERIOD_MS 300
#define PING_WS_ITERATIONS (1000 / ACCEL_READ_PERIOD_MS)

#ifdef DEBUG
#define LOG Serial.print
#define LOGF Serial.printf
#define LOGLN Serial.println
#else
#define LOG(msg)
#define LOGF(...)
#define LOGLN(msg)
#endif

static void handle_wifi_controller_status(WifiControllerStatus status);
static void handle_lora_controller_status(LoraControllerStatus status);

static void handle_robot_arm_servo(ArmAxis arm_axis, uint16_t channel);
static uint16_t get_controller_channel_value(uint8_t channel);
static uint16_t filter_signal(uint16_t* signals);
static void on_accel_data(GyroAccelData* data);
static void handle_arm_mode_changed(ArmMode mode);
static void handle_controller_disconnected(uint16_t last_sampled_signal);
static void handle_rover_mode_changed(RoverMode mode);

static const char* TAG = "ROVER_MAIN";

static uint16_t rc_values[RC_NUM_CHANNELS][RC_FILTER_SAMPLES];
static uint8_t rc_value_index = 0;

static RoverMode current_rover_mode = DRIVE_TURN_NORMAL;
static ArmMode current_arm_mode = ARM_MODE_MOVE;

static bool wifi_control_enabled = false;
static bool lora_control_enabled = false;

static RoverSwitchState startup_settings;
static bool wifi_enabled = false;

void setup() {
    Serial.begin(SERIAL_PORT_SPEED);
    Wire.begin(ROVER_SDA_PIN, ROVER_SCL_PIN);
    Wire.setClock(400000);
    xSemaphoreHandle i2cSemaphoreHandle = xSemaphoreCreateBinary();
    assert(i2cSemaphoreHandle != NULL);
    xSemaphoreGive(i2cSemaphoreHandle);

    rover_settings_switch_init();
    gyro_accel_init(i2cSemaphoreHandle, true, on_accel_data, ACCEL_READ_PERIOD_MS);
    rover_servo_init(i2cSemaphoreHandle);
    handle_controller_disconnected(0);

    rc_receiver_rmt_init();

    startup_settings = rover_settings_switch_get_state();
    if (startup_settings == ROVER_SWITCH_STATE_STATION_LORA) {
      ESP_LOGD(TAG, "Mode: ROVER_SWITCH_STATE_STATION_LORA\n");
      wifi_controller_init("RoverController", NULL, WIFI_CONTROLLER_STATION);
      wifi_enabled = true;
    } else if (startup_settings == ROVER_SWITCH_STATE_AP) {
      ESP_LOGD(TAG, "Mode: ROVER_SWITCH_STATE_AP\n");
      wifi_controller_init("Rover", NULL, WIFI_CONTROLLER_AP);
      wifi_enabled = true;
    } else {
      wifi_enabled = false;
      ESP_LOGD(TAG, "Mode: ROVER_SWITCH_STATE_LORA_ONLY\n");
    }

    if (wifi_enabled) {
      wifi_controller_register_connection_callback(&handle_wifi_controller_status);
    }

    lora_controller_init();
    lora_controller_register_connection_callback(&handle_lora_controller_status);

    init_switch_checker(RC_LOW, RC_ROVER_MODE_ROVER_CHANNEL, RC_ARM_MODE_ROVER_CHANNEL, &handle_rover_mode_changed, &handle_arm_mode_changed, wifi_enabled);

    
    rover_driving_init();
    arm_init();
    rover_head_init();

    LOGF("Rover Ready! Core: %d", xPortGetCoreID());
}

void loop() {

  if (rover_settings_switch_get_state() != startup_settings) {
    esp_restart(); // Might do graceful WiFi restart and reconfigure later, but for now this will do.
  }

  switch (current_rover_mode) {
    case DRIVE_TURN_NORMAL:
    case DRIVE_TURN_SPIN:
    {
      uint16_t motor_signal = RC_CENTER;

      rc_values[RC_STEER_CHANNEL][rc_value_index] = get_controller_channel_value(RC_STEER_CHANNEL);
      rc_values[RC_MOTOR_CHANNEL][rc_value_index] = get_controller_channel_value(RC_MOTOR_CHANNEL);
      rc_values[RC_HEAD_PITCH_CHANNEL][rc_value_index] = get_controller_channel_value(RC_HEAD_PITCH_CHANNEL);
      rc_values[RC_HEAD_YAW_CHANNEL][rc_value_index] = get_controller_channel_value(RC_HEAD_YAW_CHANNEL);

      if (current_rover_mode == DRIVE_TURN_NORMAL) {
        motor_signal = filter_signal(rc_values[RC_MOTOR_CHANNEL]);
      } else if (current_rover_mode == DRIVE_TURN_SPIN) {
        motor_signal = filter_signal(rc_values[RC_STEER_CHANNEL]);
      }

      rover_driving_move(motor_signal);
      rover_driving_steer(filter_signal(rc_values[RC_STEER_CHANNEL]));

      uint16_t yawUs = filter_signal(rc_values[RC_HEAD_YAW_CHANNEL]);
      uint16_t pitchUs = filter_signal(rc_values[RC_HEAD_PITCH_CHANNEL]);

      rover_head_yaw(yawUs);
      rover_head_pitch(pitchUs);
      break;
    }
    case ROBOT_ARM:
      if (current_arm_mode == ARM_MODE_MOVE) {
        rc_values[RC_SERVO1_CHANNEL][rc_value_index] = get_controller_channel_value(RC_SERVO1_CHANNEL);
        rc_values[RC_SERVO2_CHANNEL][rc_value_index] = get_controller_channel_value(RC_SERVO2_CHANNEL);
        rc_values[RC_SERVO3_CHANNEL][rc_value_index] = get_controller_channel_value(RC_SERVO3_CHANNEL);
        rc_values[RC_SERVO4_CHANNEL][rc_value_index] = get_controller_channel_value(RC_SERVO4_CHANNEL);

        handle_robot_arm_servo(ARM_AXIS_1, RC_SERVO1_CHANNEL);
        handle_robot_arm_servo(ARM_AXIS_2, RC_SERVO2_CHANNEL);
        handle_robot_arm_servo(ARM_AXIS_3, RC_SERVO3_CHANNEL);
        handle_robot_arm_servo(ARM_AXIS_4, RC_SERVO4_CHANNEL);
      } else if (current_arm_mode == ARM_MODE_GRIPPER) {
        rc_values[RC_SERVO5_CHANNEL][rc_value_index] = get_controller_channel_value(RC_SERVO5_CHANNEL);
        rc_values[RC_SERVO6_CHANNEL][rc_value_index] = get_controller_channel_value(RC_SERVO6_CHANNEL);

        handle_robot_arm_servo(ARM_AXIS_5, RC_SERVO5_CHANNEL);
        handle_robot_arm_servo(ARM_AXIS_6, RC_SERVO6_CHANNEL);
      }
      break;
  }
  rc_value_index = (rc_value_index + 1) % RC_FILTER_SAMPLES;

  vTaskDelay(pdMS_TO_TICKS(20));
}

static void handle_robot_arm_servo(ArmAxis arm_axis, uint16_t channel) {
  
  uint16_t speed;
  uint16_t signal = filter_signal(rc_values[channel]);
  if (signal < RC_CENTER && signal > 0) {
    signal = 2 * RC_CENTER - signal;
    speed = map(signal, RC_CENTER, RC_HIGH, ARM_MIN_SPEED, ARM_MAX_SPEED);
    arm_move_axis_us(arm_axis, RC_LOW, speed);
  } else if (signal > RC_CENTER) {
    speed = map(signal, RC_CENTER, RC_HIGH, ARM_MIN_SPEED, ARM_MAX_SPEED);
    arm_move_axis_us(arm_axis, RC_HIGH, speed);
  } else {
    arm_pause(arm_axis);
  }
}

static void handle_wifi_controller_status(WifiControllerStatus status)
{
  LOGF("Wifi Controller status: %d\n", status);
  if (status != WIFI_CONTROLLER_CONNECTED) {
    handle_controller_disconnected(0);
    wifi_control_enabled = false;
  } else {
    wifi_control_enabled = true;
  }
}

static void handle_lora_controller_status(LoraControllerStatus status)
{
  LOGF("Lora Controller status: %d\n", status);
  if (status != LORA_CONTROLLER_CONNECTED) {
    handle_controller_disconnected(0);
    lora_control_enabled = false;
  } else {
    lora_control_enabled = true;
  }
}

static uint16_t get_controller_channel_value(uint8_t channel)
{
  uint16_t channel_value = 0;

  if (lora_control_enabled) {
    channel_value = lora_controller_get_val(channel);
  } else if (wifi_control_enabled) {
    channel_value = wifi_controller_get_val(channel);
  } else {
    channel_value = rc_receiver_rmt_get_val(channel);
  }

  if (channel_value == 0) {
    channel_value = RC_CENTER;
  }

  return channel_value;
}

static uint16_t filter_signal(uint16_t* signals) {
  uint32_t signal = 0;
  for (uint8_t i = 0; i < RC_FILTER_SAMPLES; i++) {
    signal += signals[i];
  }
  signal = signal / RC_FILTER_SAMPLES;
  
  if (signal <= 800) return RC_CENTER; // If we are unlucky in timing when RC controller disconnect we might get some random low signal
  if (signal > 800 && signal < 1010) return RC_LOW;
  if (signal > 1990) return RC_HIGH;
  if (signal > 1480 && signal < 1520) return RC_CENTER;
  return signal;;
}

static void handle_rover_mode_changed(RoverMode mode) {
  LOGF("ROVER MODE CHANGED: %d\n", mode);
  current_rover_mode = mode;
  rover_driving_set_drive_mode(mode);
}

static void handle_arm_mode_changed(ArmMode mode) {
  LOGF("ARM MODE CHANGED: %d\n", mode);
  current_arm_mode = mode;
}

static void handle_controller_disconnected(uint16_t last_sampled_signal) {
  // Set all RC values to mid position if signal is 0 (controller disconnected)
  if (last_sampled_signal == 0) {
    for (uint8_t channel = 0; channel < RC_NUM_CHANNELS; channel++) {
      for (uint8_t sample = 0; sample < RC_FILTER_SAMPLES; sample++) {
        rc_values[channel][sample] = RC_CENTER;
      }
    }
  }
}

static void on_accel_data(GyroAccelData* data)
{
  if (lora_control_enabled) {
    printf("%f, %f\n", data->temp, data->gyroX); // TODO: Does not work without this print, data out of scope or something? Too tired now.
    lora_controller_send((uint8_t*)data, sizeof(GyroAccelData));
  } else if (wifi_enabled) {
    if (startup_settings == ROVER_SWITCH_STATE_AP) {
      wifi_controller_ws_send_bin((uint8_t*)data, sizeof(GyroAccelData));
    } else if (startup_settings == ROVER_SWITCH_STATE_STATION_LORA) {
      wifi_controller_udp_send_bin((uint8_t*)data, sizeof(GyroAccelData));
    }
  }

  if (wifi_enabled) {
    // To keep the ws open to the controller we need to ping it so that controller knows we did not loose connection.
    if (startup_settings != ROVER_SWITCH_STATE_AP) {
      uint8_t ping = 1;
      wifi_controller_ws_send_bin(&ping, 1);
    }
  }
}

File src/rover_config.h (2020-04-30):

#pragma once

#define SERIAL_PORT_SPEED 115200

#define RC_NUM_CHANNELS   6
#define RC_FILTER_SAMPLES 2

#define RC_LOW    1000
#define RC_CENTER 1500
#define RC_HIGH   2000

#define RC_CH1  0
#define RC_CH2  1
#define RC_CH3  2
#define RC_CH4  3
#define RC_CH5  4
#define RC_CH6  5

// Input pins connected to each channel on RC Receiver
#define RC_CH1_INPUT  34
#define RC_CH2_INPUT  35
#define RC_CH3_INPUT  4
#define RC_CH4_INPUT  39
#define RC_CH5_INPUT  25
#define RC_CH6_INPUT  36

#define RC_STEER_CHANNEL      RC_CH1
#define RC_MOTOR_CHANNEL      RC_CH2
#define RC_HEAD_YAW_CHANNEL   RC_CH3
#define RC_HEAD_PITCH_CHANNEL RC_CH4

#define RC_SERVO1_CHANNEL RC_CH1
#define RC_SERVO2_CHANNEL RC_CH2
#define RC_SERVO3_CHANNEL RC_CH4
#define RC_SERVO4_CHANNEL RC_CH3
#define RC_SERVO5_CHANNEL RC_CH1
#define RC_SERVO6_CHANNEL RC_CH2

#define RC_ROVER_MODE_ROVER_CHANNEL RC_CH5
#define RC_ARM_MODE_ROVER_CHANNEL   RC_CH6


#define ARM_NUM_AXIS 6

#ifdef NINA_W10
#define ROVER_SCL_PIN               5
#define ROVER_SDA_PIN               23
#else
#define ROVER_SCL_PIN               22
#define ROVER_SDA_PIN               21
#endif

#define SERVOMIN  250 // this is the 'minimum' pulse length count (out of 4096)
#define SERVOMAX  500 // this is the 'maximum' pulse length count (out of 4096)

#define SERVOMIN_FULL_RANGE  150 // this is the 'minimum' pulse length count (out of 4096)
#define SERVOMAX_FULL_RANGE  600 // this is the 'maximum' pulse length count (out of 4096)

#define ROVER_MOTORS_LEFT_PIN       17
#define ROVER_MOTORS_RIGHT_PIN      13

#define ROVER_SETTINGS_SWITCH_1     2
#define ROVER_SETTINGS_SWITCH_2     23

// Offset used in rover_servo to make 
#define SERVO_FRONT_LEFT_OFFSET     (+20)
#define SERVO_FRONT_RIGHT_OFFSET    (-15)
#define SERVO_BACK_LEFT_OFFSET      (+5)
#define SERVO_BACK_RIGHT_OFFSET     (-25)

const uint16_t config_default_ch_values[RC_NUM_CHANNELS] = { RC_CENTER, RC_CENTER, RC_CENTER, RC_CENTER, RC_LOW, RC_CENTER };

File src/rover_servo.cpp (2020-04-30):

#include <Arduino.h>
#include "rover_servo.h"
#include "freertos/FreeRTOS.h"
#include "freertos/task.h"
#include "ESP32Servo.h"
#include "rover_config.h"
#include "esp_timer.h"
#include "esp_err.h"
#include "assert.h"

#include <Wire.h>
#include <Adafruit_PWMServoDriver.h>

#define ADAFRUIT_PWM_EXPANDER_ADDR  0x40

#define SERVO_UPDATE_INTERVAL_MS  10

typedef enum ServoDirection {
  DIRECTION_POSITIVE,
  DIRECTION_NEGATIVE
} ServoDirection;

typedef struct ServoState {
  uint16_t      min;
  uint16_t      max;
  uint16_t      current_pos;
  uint16_t      start_pos;
  uint16_t      end_pos;
  uint8_t       speed;
  uint32_t      num_moves;
  uint32_t      steps_per_move;
  uint32_t      num_moves_finished;
  ServoDirection direction;
  bool          isPaused;
  xList         path;
} ServoState;

static void update_servo_positions_timer_cb(void* arg);
static void reset_moving_servo(RoverServoId servoId);
static uint16_t calibrated_servo_map(RoverServoId servoId, uint16_t us, uint16_t in_low, uint16_t in_high, uint16_t out_low, uint16_t out_high);

static xSemaphoreHandle position_update_sem_handle;
static xSemaphoreHandle i2cSemaphoreHandle;

static Adafruit_PWMServoDriver servo_driver = Adafruit_PWMServoDriver(ADAFRUIT_PWM_EXPANDER_ADDR, Wire);
static bool isInitialized = false;
static ServoState servo_states[SERVO_LAST];

void rover_servo_init(xSemaphoreHandle i2cSemHandle) {
  TaskHandle_t xHandle = NULL;
  if (!isInitialized) {
    isInitialized = true;
    memset(&servo_states, 0, sizeof(servo_states));
    for (uint8_t i = 0; i < SERVO_LAST; i++) {
      servo_states[i].current_pos = RC_CENTER;
    }
    i2cSemaphoreHandle = i2cSemHandle;
    assert(pdTRUE == xSemaphoreTake(i2cSemaphoreHandle, pdMS_TO_TICKS(100)));
    servo_driver.begin();
    servo_driver.setPWMFreq(60);
    xSemaphoreGive(i2cSemaphoreHandle);
    position_update_sem_handle = xSemaphoreCreateBinary();
    assert(position_update_sem_handle);
    xSemaphoreGive(position_update_sem_handle);

    assert(xTaskCreate(update_servo_positions_timer_cb, "ServoUpdater", 2048, NULL, tskIDLE_PRIORITY, &xHandle) == pdPASS);
  }
}

void rover_servo_write(RoverServoId servoId, uint16_t us, bool full_range)
{
  assert(servoId < SERVO_LAST);
  assert(us >= RC_LOW);
  assert(us <= RC_HIGH);
  xSemaphoreTake(position_update_sem_handle, portMAX_DELAY);
  uint16_t pwm_value;
  if (full_range) {
    pwm_value = map(us, RC_LOW, RC_HIGH, SERVOMIN_FULL_RANGE, SERVOMAX_FULL_RANGE);
  } else {
    pwm_value = calibrated_servo_map(servoId, us, RC_LOW, RC_HIGH, SERVOMIN, SERVOMAX);
  }

  reset_moving_servo(servoId);
  servo_states[servoId].current_pos = us;

  assert(pdTRUE == xSemaphoreTake(i2cSemaphoreHandle, pdMS_TO_TICKS(1000)));
  servo_driver.setPWM((uint8_t)servoId, 0, pwm_value);
  xSemaphoreGive(i2cSemaphoreHandle);
  xSemaphoreGive(position_update_sem_handle);
}

void rover_servo_move(RoverServoId servoId, uint16_t pos, uint8_t speed)
{
  assert(servoId < SERVO_LAST);
  ServoState* servo_state = &servo_states[servoId];
  uint32_t steps_to_move;
  uint32_t internal_speed;
  assert(pos >= RC_LOW);
  assert(pos <= RC_HIGH);
  assert(speed >= SERVO_MIN_SPEED);
  assert(speed <= SERVO_MAX_SPEED);
  internal_speed = SERVO_MAX_SPEED + 1 - speed; // Speed is inverted internally 1 fastest, 10 slowest

  if (pos == servo_state->current_pos || (pos == servo_state->end_pos && internal_speed == servo_state->speed)) return;
  xSemaphoreTake(position_update_sem_handle, portMAX_DELAY);
  servo_state->isPaused = false;
  servo_state->end_pos = pos;
  servo_state->start_pos = servo_state->current_pos;
  servo_state->speed = internal_speed;
  steps_to_move = abs(servo_state->end_pos - servo_state->current_pos);
  servo_state->num_moves = (steps_to_move / SERVO_UPDATE_INTERVAL_MS);
  if (servo_state->num_moves == 0) {
    servo_state->num_moves = 1;
  }
  servo_state->steps_per_move = steps_to_move / servo_state->num_moves;
  servo_state->num_moves_finished = 0;
  servo_state->direction = (servo_state->end_pos > servo_state->current_pos) ? DIRECTION_POSITIVE : DIRECTION_NEGATIVE;
  xSemaphoreGive(position_update_sem_handle);
}

void rover_servo_pause(RoverServoId servoId)
{
  assert(servoId < SERVO_LAST);
  servo_states[servoId].isPaused = true;
}

void rover_servo_resume(RoverServoId servoId)
{
  assert(servoId < SERVO_LAST);
  servo_states[servoId].isPaused = false;
}

static void update_servo_positions_timer_cb(void* arg)
{
  while (true) {
    ServoState* axis;
    uint32_t next_servo_pos;
    for (uint8_t i = 0; i < SERVO_LAST; i++) {
      axis = &servo_states[i];
      if (axis->num_moves == 0) continue;
      if (axis->isPaused) continue;
      xSemaphoreTake(position_update_sem_handle, portMAX_DELAY);
      axis->num_moves_finished++;
      if (axis->num_moves_finished % axis->speed == 0) {
        // Check if last move
        if (abs(axis->current_pos - axis->end_pos) <= axis->steps_per_move) {
          axis->current_pos = axis->end_pos;
          next_servo_pos = axis->end_pos;
          axis->num_moves = 0;
          axis->num_moves_finished = 0;
          axis->start_pos = axis->current_pos;
        } else if (axis->direction == DIRECTION_POSITIVE) {
          next_servo_pos = axis->current_pos + axis->steps_per_move;
          axis->current_pos = axis->current_pos + axis->steps_per_move;
        } else {
          next_servo_pos = axis->current_pos - axis->steps_per_move;
          axis->current_pos = axis->current_pos - axis->steps_per_move;
        }
        xSemaphoreGive(position_update_sem_handle);
        rover_servo_write((RoverServoId)i, next_servo_pos, true);
      } else {
        xSemaphoreGive(position_update_sem_handle);
      }
    }
    vTaskDelay(pdMS_TO_TICKS(SERVO_UPDATE_INTERVAL_MS));
  }
}

static void reset_moving_servo(RoverServoId servoId)
{
  assert(servoId < SERVO_LAST);
  memset(&servo_states[servoId], 0 , sizeof(ServoState));
  servo_states[servoId].isPaused = true;
}

static uint16_t calibrated_servo_map(RoverServoId servoId, uint16_t us, uint16_t in_low, uint16_t in_high, uint16_t out_low, uint16_t out_high)
{
  uint16_t val = map(us, in_low, in_high, out_low, out_high);
  
  switch (servoId) {
    case SERVO_FRONT_LEFT:
      val += SERVO_FRONT_LEFT_OFFSET;
      break;
    case SERVO_FRONT_RIGHT:
      val += SERVO_FRONT_RIGHT_OFFSET;
      break;
    case SERVO_BACK_LEFT:
      val += SERVO_BACK_LEFT_OFFSET;
      break;
    case SERVO_BACK_RIGHT:
      val += SERVO_BACK_RIGHT_OFFSET;
      break;
    default:
      break;
  }

  if (val < SERVOMIN_FULL_RANGE) {
    val = SERVOMIN_FULL_RANGE;
  } else if (val > SERVOMAX_FULL_RANGE) {
    val = SERVOMAX_FULL_RANGE;
  }

  return val;
}

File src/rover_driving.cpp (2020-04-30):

#include "esp_system.h"
#include "rover_driving.h"
#include "rover_config.h"
#include "rover_servo.h"
#include <ESP32Servo.h>

static void steer_normal(uint16_t signal);
static void steer_spin(uint16_t signal);

enum MotorDirection {
  MOTOR_IDLE,
  MOTOR_FORWARD,
  MOTOR_BACKWARD
};

static Servo motors_left;
static Servo motors_right;

static MotorDirection motor_state = MOTOR_IDLE;
static RoverMode current_rover_mode = DRIVE_TURN_NORMAL;

void rover_driving_init(void)
{
    motors_left.attach(ROVER_MOTORS_LEFT_PIN);
    motors_left.writeMicroseconds(RC_CENTER);
    motors_right.attach(ROVER_MOTORS_RIGHT_PIN);
    motors_right.writeMicroseconds(RC_CENTER);

    // Steering servos
    rover_servo_write(SERVO_FRONT_LEFT, RC_CENTER);
    rover_servo_write(SERVO_FRONT_RIGHT, RC_CENTER);
    rover_servo_write(SERVO_BACK_LEFT, RC_CENTER);
    rover_servo_write(SERVO_BACK_RIGHT, RC_CENTER);
}

static void setMotorInReverseMode(Servo motor) {
  motor.writeMicroseconds(1400);
  delay(100);
  motor.writeMicroseconds(RC_CENTER);
  delay(100);
}

void rover_driving_set_drive_mode(RoverMode mode)
{
    current_rover_mode = mode;
}

void rover_driving_move(uint16_t signal) {
  switch (current_rover_mode) {
    case DRIVE_TURN_NORMAL:
        if (signal < RC_CENTER && signal > 0) { // MOTOR_Backward        
          // When going from MOTOR_forward/MOTOR_idle to reverse, motors (ESC) need to be set in reverse mode
          if (motor_state == MOTOR_IDLE) {
              setMotorInReverseMode(motors_left);
              setMotorInReverseMode(motors_right);
              motor_state = MOTOR_BACKWARD;
          }
        
      } else if (signal > RC_CENTER) {
        motor_state = MOTOR_FORWARD;
      } else {
        motor_state = MOTOR_IDLE;
      }
      motors_left.writeMicroseconds(signal);
      motors_right.writeMicroseconds(signal);
      break;
    case DRIVE_TURN_SPIN:
      {
        uint16_t diff = abs((int16_t)RC_CENTER - (int16_t)signal);

        if (signal < RC_CENTER && signal > 0) { // Spin Anticlockwise
          if (motor_state == MOTOR_IDLE) {
            setMotorInReverseMode(motors_left);
            motor_state = MOTOR_FORWARD;
          }
          motors_right.writeMicroseconds(RC_CENTER + diff);
          motors_left.writeMicroseconds(RC_CENTER - diff);
        } else if (signal > RC_CENTER) {
          if (motor_state == MOTOR_IDLE) {
            setMotorInReverseMode(motors_right);
            motor_state = MOTOR_FORWARD;
          }
          motors_right.writeMicroseconds(RC_CENTER - diff); // Spin Clockwise
          motors_left.writeMicroseconds(RC_CENTER + diff);
        } else {
          motor_state = MOTOR_IDLE;
          motors_left.writeMicroseconds(signal);
          motors_right.writeMicroseconds(signal);
        }
        break;
      }
    default:
      break;
  }

}

void rover_driving_steer(uint16_t signal) {
  switch (current_rover_mode) {
    case DRIVE_TURN_NORMAL:
      steer_normal(signal);
      break;
    case DRIVE_TURN_SPIN:
      steer_spin(signal);
      break;
    default:
      break;
  }
}

static void steer_normal(uint16_t signal)
{
  uint16_t diff = abs((int16_t)RC_CENTER - (int16_t)signal);
  if (signal < RC_CENTER && signal > 0) { // Left turn
      rover_servo_write(SERVO_FRONT_LEFT, RC_CENTER - diff);
      rover_servo_write(SERVO_FRONT_RIGHT, RC_CENTER - diff);
      rover_servo_write(SERVO_BACK_LEFT, RC_CENTER + diff);
      rover_servo_write(SERVO_BACK_RIGHT, RC_CENTER + diff);
  } else if (signal > RC_CENTER) { // Right turn
      rover_servo_write(SERVO_FRONT_LEFT, RC_CENTER + diff);
      rover_servo_write(SERVO_FRONT_RIGHT, RC_CENTER + diff);
      rover_servo_write(SERVO_BACK_LEFT, RC_CENTER - diff);
      rover_servo_write(SERVO_BACK_RIGHT, RC_CENTER - diff);
  } else {
    rover_servo_write(SERVO_FRONT_LEFT, RC_CENTER);
    rover_servo_write(SERVO_FRONT_RIGHT, RC_CENTER);
    rover_servo_write(SERVO_BACK_LEFT, RC_CENTER);
    rover_servo_write(SERVO_BACK_RIGHT, RC_CENTER);
  }
}

static void steer_spin(uint16_t signal)
{
  rover_servo_write(SERVO_FRONT_LEFT, RC_HIGH);
  rover_servo_write(SERVO_FRONT_RIGHT, RC_LOW);
  rover_servo_write(SERVO_BACK_LEFT, RC_HIGH);
  rover_servo_write(SERVO_BACK_RIGHT, RC_LOW);
}

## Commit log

2019-08-18 Controlling 3 servoes with RC Controller
2019-08-18 Switch between different modes, normal drive, turn on spot and robot arm control.
2019-08-25 Add filter of 5 samples to filter out small spikes in signal
2019-09-05 Adds ability to turn on the spot by running each side of motors in opposite direction.
2019-09-08 Use switch on ch6 to switch between moving arm and gripper
2019-09-08 Add Fusion 360 CAD project and step files.
2019-10-12 Port to ESP32. Use ESP32 RMT peripheral for reading Receiver PINs. Implemented simple Servo easing and extracted arm logic.
2019-10-22 Add reading of MPU6050 Gyra/Accelerometer. Not doing anything yet witth the data.
2019-10-23 Use a I2C Servo expander to free up pins on the ESP32. For now only the 6 arm servos use it.
2019-10-24 Created a simple website hosted on the ESP32 itself for driving the Rover.
    Website sets up a websocket to the ESP32 and data is then sent on it.
2019-10-29 Always start AP, when websocket is opened automatically switch to wifi control of rover
2019-11-01 Use PWM expander for all servos
2019-11-11 Add buttons in web controller for changing the Rover driving mode
2019-11-12 Protect I2C servo driver as multiple tasks can use it at the same time
2019-11-17 Fix registrating to wifi_controller before its initiated. Use default channel values when no controller connected
    [main.cpp, rc_receiver_rmt.cpp, rover_config.h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]
2019-11-17 Add option to use the half or full Servo movement range when writing to a servo.
2019-11-17 Change how driving works a bit when controlling over wifi
    If Normal Rover Drive mode use right joystick for steering
    and left for forward/backward and ignore other value.
    Makes it a bit easier to drive and to avoid accidentally
    going forward when you want to just steer.
2019-12-05 Gave the Rover a head. Head supports yaw and pitch movement.
2019-12-30 Simplify gyro data reading
2020-01-03 Add camera LED control button.
2020-01-04 Move common servo control logic from arm.c to rover_servo.c
2020-01-04 Button for toggling camera feed. Reconnect if ws disconnects.
2020-01-04 Update CAD files and images
2020-01-06 Send gyro/accel data over the websocket.
2020-01-14 Cad: Add missing holes in the main body.
2020-03-04 CAD: Added room for wires in parts so wires from DC motors and steering servos can be routed inside. Add 2020 rover styled wheel option that can be printed in flex/TPU for better grip.
    [rover_2020_wheel_flex.f3d]
2020-04-20 Change websocket server library => fixes random crashes.
    [main.cpp, wifi_controller.cpp]
2020-04-23 Correct servo model for steering. Fixes https://github.com/jakkra/Mars-Rover/issues/10
2020-04-25 Modify pin config for new LoRa board
2020-04-25 Handle switching between LoRa and WiFi for TX
2020-04-25 Add a switch to determine which mode AP-LORA/STA-LORA/LORA-ONLY to use.
2020-04-26 More clerance for steering servos. Fixes https://github.com/jakkra/Mars-Rover/issues/10.
2020-04-27 Fix margins around steering servos. https://github.com/jakkra/Mars-Rover/issues/10
2020-04-28 Add calibration option so that steering wheels point straight.
2020-04-30 Use a task instead of timer for handling servo position updates.
2020-05-21 Change LoRa freq. Fix LoRa connected/disconnected bug.
    [lora_controller.cpp, main.cpp]
2020-05-26 Fix crashes in LoRa lib when used together with I2C, due to LoRa lib spending to much time in data availible ISR.
    [lora_controller.cpp, main.cpp]
2020-05-26 Move LoRa isr registration after tasks are created, fixes assert due to tasks not created when isr hit.
    [lora_controller.cpp]
2020-06-19 Update DC motor description in README
2020-06-23 CAD: Remove unused parts in the head. Make it clear how to parts are fit together. Fixes https://github.com/jakkra/Mars-Rover/issues/17
2020-10-08 CAD: Convert sketch to one file due to licence changes of Fusion 360 free version. It no longer support enough active documents in free version for original rover version.
2021-02-13 CAD: Update back leg connector to be able to route wires through it.
2021-12-18 Added more cosmetics to the rover, such as high gain antenna that can be rotated.
2022-10-29 CAD: Fixes #27, unhide the arm in the model.
